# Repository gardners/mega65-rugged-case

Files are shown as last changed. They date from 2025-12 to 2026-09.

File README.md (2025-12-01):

# mega65-rugged-case
MEGA65 / MEGAphone Rugged Case Design

Designed to fit a MEGA65 (plus MEGAphone communications hardware)
into a Tactix Large Tough Case

See https://c65gs.blogspot.com/2025/12/megaphone-case-design.html for more information.

Detailed assembly instructions will be developed going forward (it's initially intended only for the MEGAphone development team to implement), as we get community members to replicate it, but it is fairly self-explanatory as you go through, with the following points:
1. The upper file is for the LCD panel and driver boards. 
2. The four lower cuts are for the keyboard, floppy drive, MEGA65 FPGA board and ancilliaries and cellular module plus battery, respectively.
3. All fixings are M3.  All panel spacers are 25mm metal spacers to suit M3 screws.  All fixings and spacers can be purchased in Australia from Jaycar Electronics.  Equivalents will be easily available in other countries.
4. Once the full deck is assembled, it slides fairly easily into the lower-shell of the case, but fits snugly enough that it doesn't need fixing in place.
5. The LCD panel bezel assembly does need fixing in place, and the panel cut-out that holds the driver boards can be laid against the rear of the lid, centred horizontally, and used as a guide for drilling the 3mm holes in the lid.  The vertical positioning pieces allow for vertical adjustment of the position of the panel and it's screws through the case lid, so that the exact vertical positioning of the holes in the lid do not need to be precise, which can otherwise be difficult to achieve.

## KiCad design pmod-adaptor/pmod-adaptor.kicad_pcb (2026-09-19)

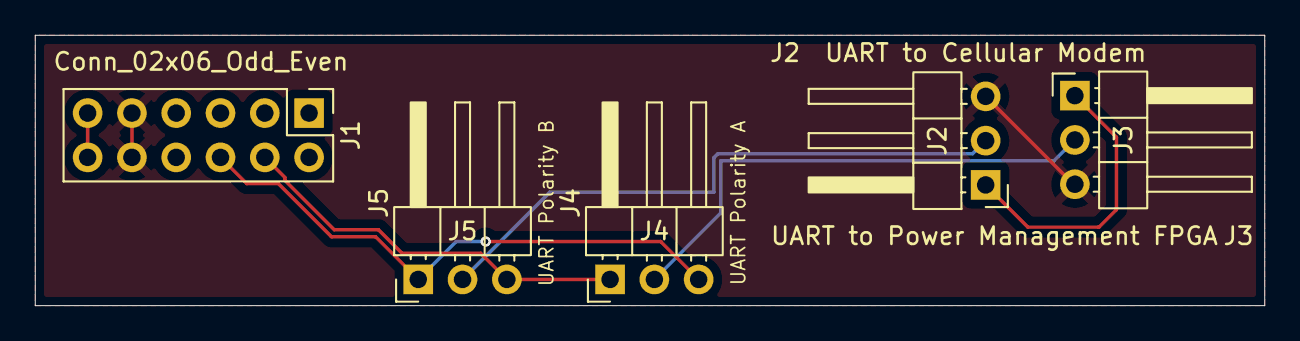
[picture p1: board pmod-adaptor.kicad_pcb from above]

Board: 2 copper layers, 70.5 x 15.5 mm, 5 parts (0 on the bottom side), 7 nets.

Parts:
J1: Conn_02x06_Odd_Even; PinHeader_2x06_P2.54mm_Vertical
J2: UART to Cellular Modem; PinHeader_1x03_P2.54mm_Horizontal
J3: UART to Power Management FPGA; PinHeader_1x03_P2.54mm_Horizontal
J4: UART Polarity A; PinHeader_1x03_P2.54mm_Horizontal
J5: UART Polarity B; PinHeader_1x03_P2.54mm_Horizontal

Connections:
+3V3: J1.11, J1.12
GND: J1.9, J1.10, J2.3, J3.3
PMOD1_4: J1.4, J4.1, J5.3
PMOD1_6: J1.6, J4.3, J5.1
UART_A: J3.2, J4.2
UART_B: J2.2, J5.2
UART_RELAY: J2.1, J3.1

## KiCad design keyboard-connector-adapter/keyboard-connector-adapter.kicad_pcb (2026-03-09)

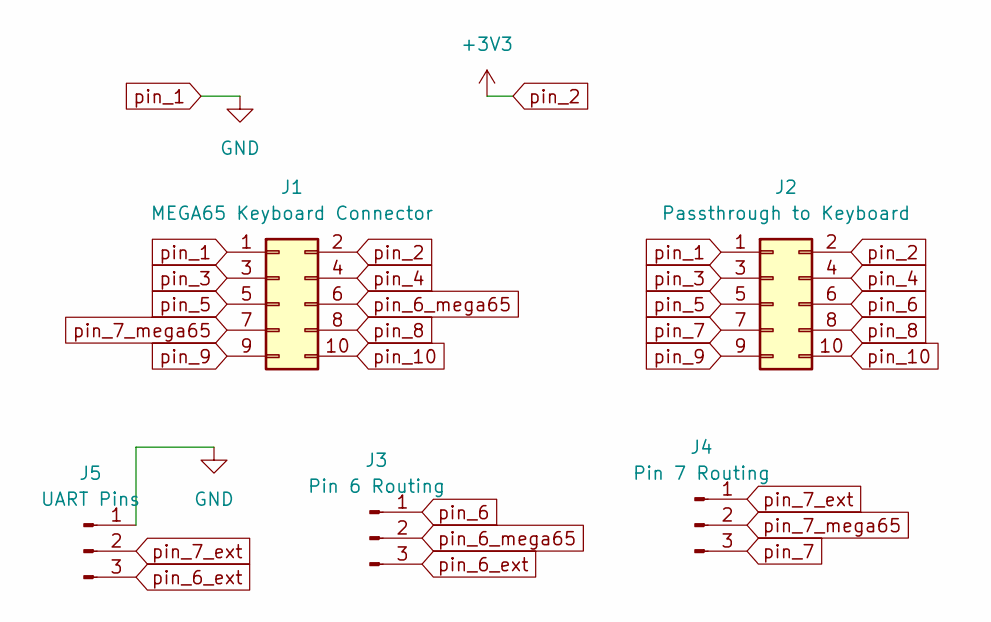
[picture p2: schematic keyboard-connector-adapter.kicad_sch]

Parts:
J1: MEGA65 Keyboard Connector; PinSocket_2x05_P2.54mm_Vertical
J2: Passthrough to Keyboard; PinHeader_2x05_P2.54mm_Horizontal
J3: Pin 6 Routing; PinHeader_1x03_P2.54mm_Horizontal
J4: Pin 7 Routing; PinHeader_1x03_P2.54mm_Horizontal
J5: UART Pins; PinHeader_1x03_P2.54mm_Horizontal

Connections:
pin_1: J1.1, J2.1, J5.1
pin_2: J1.2, J2.2
pin_3: J1.3, J2.3
pin_4: J1.4, J2.4
pin_5: J1.5, J2.5
pin_6: J2.6, J3.1
pin_6_ext: J3.3, J5.3
pin_6_mega65: J1.6, J3.2
pin_7: J2.7, J4.3
pin_7_ext: J4.1, J5.2
pin_7_mega65: J1.7, J4.2
pin_8: J1.8, J2.8
pin_9: J1.9, J2.9
pin_10: J1.10, J2.10

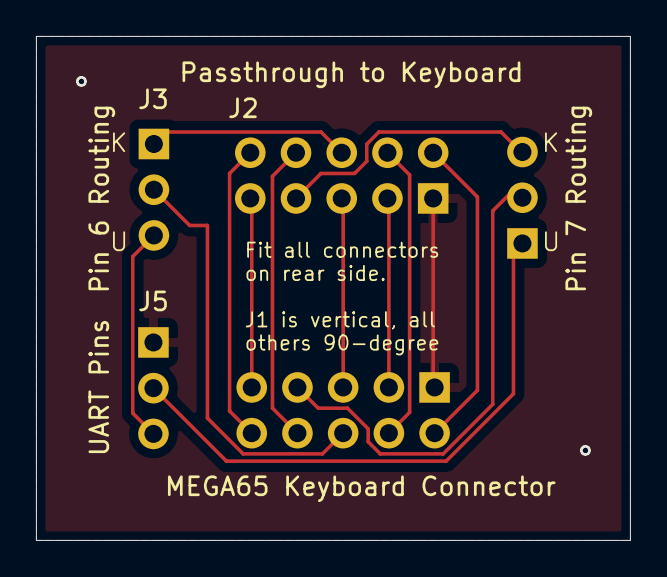
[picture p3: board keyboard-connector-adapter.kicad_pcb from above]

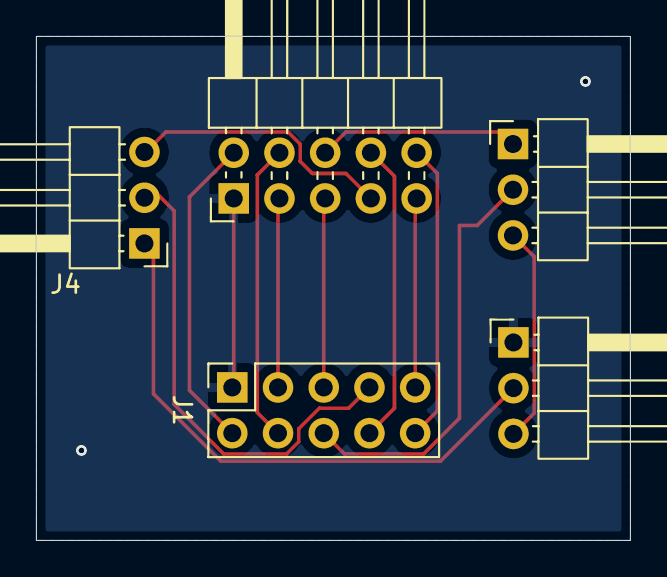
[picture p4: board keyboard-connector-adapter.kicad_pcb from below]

Board: 2 copper layers, 33.0 x 28.0 mm, 5 parts (5 on the bottom side), 14 nets.

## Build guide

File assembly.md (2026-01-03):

## Lower Half

0. Laser cut each of the panels.
1. Solder ~50cm leads onto two momentary action switches for the POWER and BOOT buttons (I used https://www.jaycar.com.au/dpdt-quality-pushbutton/p/SP0714).
   Put female dupont (0.1" female header) connectors on the ends of these leads.  They should be short-circuit when the buttons are pressed and
   open circuit when not pressed.
2. Assemble the keyboard panel (lower-laser-cut.svg) and fit either a MEGA65 retail keyboard or a MEGA65 DIY keyboard and the two push-buttons from the previous step.
3. Assemble the floppy drive panel (lower-deck-2-laser-cut.svg), fitting a standard PC 1.44MB floppy drive.
   Yoo should also add floppy data cable and floppy power cable at this point, as feeding them through later may be difficult.
   If you don't have a floppy drive, you will need a spacer of the same height.
4. Use M3x6mm screws to connect the two together where the holes line up with threaded hexes from the other panel.
5. Solder a header onto J2 of a https://github.com/svenpetersen1965/C64---Cart64out board. You don't need any other parts on it.
6. Solder ~30cm leads onto one or two speakers. I'm lazy and just used more female dupont connectors.
   But you can use the correct JLC connectors for J19 and J22 on a MEGA65 R3 board.
7. Fit the MEGA65 main board to the panel, by inserting the M3x15 screws from the rear, fitting the HEX6.3s and then lowering the mainboard onto the produding screws.
   Use nylon NUT+WASHERs to fix the board in place.
8. Use M3x15 screws and HEX6.3s to screw the speakers into the panel, and then connect to J19 and/or J22 as desired.
9. Fit the TE0790 JTAG adapter now (if you did it before, it would have blocked access to a screw).
10. Fit the retaining M3x25 for the expansion breakout board from the rear, then put a HEX6.3 + NUT+WASHER to hold that in place and vertically space the support for the expansion board.
11. Fit the expansion port breakout board and secure with nylon NUT+WASHER.
12. Prepare high-current battery leads.  I use one or two 3.2V 10Ah monolithic LiFePO4 cells.
    The cells I bought use 5mm diameter screw terminals, so I am using nylon lock-nuts to hold ring connectors firmly in place.
    A low-resistance connection is important, because with a 1S configuration and nearly-flat batteries currents of ~10A are possible.
    It's a good idea to put an in-line fuse in there.
    You need two sets of leads from the batteries: One is the high-current one used to generate the 12V (probably 9V in reality if you
    use the same DC:DC eval board that I'm using).
    The other is for the 5V for the cellular modem.  That one can't draw quite as much, but peak currents of 5A - 8A from a nearly flat
    battery are still quite possible, even if the average current draw will be quite a bit lower.
    The DC:DC eval board is a bit annoying on several fronts. One, it has not mounting holes to screw it into place, so it has to get kind of wedged
    between spacers. Another is that it defaults to 9V, and they didn't bother making it easy to tune the output voltage.
    And the third is it just has big peg connectors, so you have to solder the leads onto it.
    The battery leads need to be about 30cm long.

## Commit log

2025-11-15 begin designing laser-cut upper piece for LCD panel
2025-11-15 add more holes etc
2025-11-15 update upper design SVG based on first laser-cut attempt
2025-11-15 begin drawing top-plate for lower half
2025-11-22 refinements from next test cut. add phone and disk access cut-outs
2025-11-22 add extra holes for lid mounting
2025-11-22 add LCD panel cables cut-out
2025-11-22 add securing holes to next deck below keyboard
2025-11-22 adjustments based on next laser cut run
2025-11-22 more refinements following laser cut. path subtractions
2025-11-22 more refinement following more prints
2025-11-24 make upper bracket vertically adjustable
2025-11-29 further refining lower case
2025-11-30 more adjustments to lower case
2026-01-03 adjust lower laser cut for MK-II keyboard
2026-01-03 add assembly labels to keyboard deck
2026-01-03 more assembly instructions
2026-01-03 begin assembly instructions
2026-01-03 work on assembly instructions
2026-01-03 improve POWER and BOOT label positions for switch clearance
2026-01-03 correct hole positions for 5V regulator for cellular modem
2026-01-03 enlarge hole to allow 12V DC:DC to pass through the hole.
2026-01-04 add provision for isolator switch and phone cord path.
2026-03-09 add keyboard connector adaptor PCB
    [keyboard-connector-adapter.kicad_pcb, keyboard-connector-adapter.kicad_sch]
2026-03-09 plot drill and gerbers
    [keyboard-connector-adapter.kicad_pcb]
2026-03-14 incorporate feedback from Dione following latest test cut
2026-09-19 add pmod adaptor design
    [pmod-adaptor.kicad_pcb, pmod-adaptor.kicad_sch]
2026-09-26 add mounting holes for terminal block
2026-09-27 fix terminal block hole position
2026-10-05 add wiring loom for prototype.
